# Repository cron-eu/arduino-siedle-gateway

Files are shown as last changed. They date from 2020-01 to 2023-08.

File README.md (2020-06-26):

Arduino Doorbell
====



Abstract
----

This repository holds the documentation and software needed to build a Slack interface to our Siedle Doorbell-System, using an Arduino MKR 1010 WiFi board and some electronics.

Project Folder Structure
---

* `firmware/**` Firmware for the Arduino MKR1010 WiFi Board (C++)
* `doc/*` Documentation Files (Markdown)

Author
----

Remus Lazar (rl -at- cron dot eu)

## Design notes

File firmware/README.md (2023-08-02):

Arduino Doorbell Firmware
====

Abstract
----

Firmware related documentation, how to build and configure the Hardware for operation.

#### Development Setup

Instructions how to setup the whole project (install platformio, CLion related stuff) can be found [here](../doc/Setup.md).

Device Setup and Configuration
----

An Overview about how the software and hardware works and guide to setup and configure the hardware.

Technical Overview
---

### Receive

The Arduino uses a simple hardware for the power supply and also for converting the Siedle Bus voltage to a range compatible with the SAMD21 micro (which uses 3.3V supply).

Using an ISR (interrupt service routine) the Arduino Firmware listens on the Siedle bus and captures all incoming messages, posting them using MQTT.

The messaged posted are simple JSON messages like:

```json
{
 "ts": 1580122760,
 "cmd": 1151144720
}
``` 

`ts` being the unix timestamp (UTC, synchronized via NTP), the `cmd` being the command itself - which is a 32 Bit unsigned integer.

The communication with the AWS MQTT Broker is encrypted with an X.509 certificate (see below).

### Transmit

Currently not implemented, WIP.

### Crypto Chip, X.509 Certificate (MKR Series)

To use X.509 certificates for authentication it is required that the ECC608A crypto element is configured and locked.

#### Generate the Private Key

Note: Since the private key is generated inside the crypto element it never leaves the device and is stored securely and cannot be read.

See [Configuring and Adding the Board to AWS IoT Core](https://create.arduino.cc/projecthub/Arduino_Genuino/securely-connecting-an-arduino-mkr-wifi-1010-to-aws-iot-core-a9f365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) for how to do this.

In a nutshell:
* Open the Arduino IDE
* Install the `ArduinoECCX08` Library and dependencies
* Select the MKR WiFi 1010 Board from the menu
* RUN File -> Examples -> ArduinoECCX08 -> Tools -> ECCX08CSR
* Use the Name "ArduinoDoorbell" for the "Common Name", all other fields can be left blank
* Copy the generated CSR text including "-----BEGIN CERTIFICATE REQUEST-----" and "-----END CERTIFICATE REQUEST-----" and save it locally.

### Crypto, X.509 Certificates (ESP8266)

See [Marrying ESP8266 & AWS IoT Blog Post](https://medium.com/@jgillard/marrying-esp8266-aws-iot-69f1ab219c2).

In a nutshell:

Go to the AWS IoT console, create a new device and create also the certificates, then:

```bash
cid=d9f9d3a15a
openssl x509 -in ~/Downloads/${cid}-certificate.pem.crt -out data/cert.der -outform DER 
openssl rsa -in ~/Downloads/${cid}-private.pem.key -out data/private.der -outform DER
openssl x509 -in ~/Downloads/AmazonRootCA1.pem.txt -out data/ca.der -outform DER
```

To upload the certificates:

```bash
pio run -e esp --target uploadfs
```

#### Existing Devices

* Arduino MKR WIFI 1010
  * Common Name: "ArduinoDoorbell"
* Arduino nano 33
  * Common Name: "ArduinoDoorbellNano"
* ESP8266 d1-mini
  * Common Name: "ArduinoDoorbellESP"

"Every Day" Actions
----

### Build and Upload

There are two targets in the Makefile for that: `make build` and `make upload`.

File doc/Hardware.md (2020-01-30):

Arduino Doorbell, Hardware
====

Arduino
----

### [ARDUINO MKR WIFI 1010](https://store.arduino.cc/arduino-mkr-wifi-1010)

<p>
  
</p>

See the [Getting Started](https://www.arduino.cc/en/Guide/MKRWiFi1010) document for a broad overview which available libraries are already available for this board.

### [ARDUINO NANO 33 IOT](https://store.arduino.cc/arduino-nano-33-iot)

<p>
  
</p>

Arduino related
----

* [Securely Connecting an Arduino MKR WiFi 1010 to AWS IoT Core](https://create.arduino.cc/projecthub/Arduino_Genuino/securely-connecting-an-arduino-mkr-wifi-1010-to-aws-iot-core-a9f365)

* [ArduinoMqttClient Library for Arduino](https://github.com/arduino-libraries/ArduinoMqttClient)

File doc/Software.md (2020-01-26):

WiFi/MQTT Software and Libraries
====

MQTT, SSL and related libraries
----

* [Official Arduino MQTT Library](https://github.com/arduino-libraries/ArduinoMqttClient)
* [ArduinoMqttClient Library for Arduino](https://github.com/arduino-libraries/ArduinoMqttClient)
* [ArduinoBearSSL](https://github.com/arduino-libraries/ArduinoBearSSL)
* [ArduinoECCX08](https://github.com/arduino-libraries/ArduinoECCX08)

Arduino Cloud Provider Examples
----

See https://github.com/arduino/ArduinoCloudProviderExamples

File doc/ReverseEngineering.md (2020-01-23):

Reverse Engineering Insights
====

Siedle 1+n protocol
----

Basically this uses different voltages to signalize the events, e.g. "ringing".

* [Offizielles Systemhandbuch](https://www.siedle.de/xs_db/DOKUMENT_DB/www/Systemhandbuch/1+n_2013/Systemhandbuch_1+n-Technik_136441_DE.pdf)
* [Klingelanlage: Siedle "1+n" Protokoll  (DE)](https://www.mikrocontroller.net/topic/264481)
* [Reverse engineering of the Siedle HTA 811-0 W (DE)](https://www.richis-lab.de/Siedle.htm)

Siedle In-Home-Bus Protokoll
----

Newer Siedle devices use a bus protocol called "In-Home-Bus". The bus is a 2-wire bus and uses a supply voltage of 28V. Devices do communicate via monitoring the bus voltage and also pulling down the bus to transmit individual bits.

The cheapest Siedle Device is the BTS 850 (~50 €).

There is a blog post on mikrocontroller.net about [building a WiFi enabled MQTT Gateway](https://www.mikrocontroller.net/topic/308271) based on an Arduino, the C source code also [being available](https://www.mikrocontroller.net/attachment/360089/siedle-client.ino).

### Gyrator Circuit

See the [Eingangskondensator dämpft Audio auf Busleitung](https://www.mikrocontroller.net/topic/343694) form article for details.

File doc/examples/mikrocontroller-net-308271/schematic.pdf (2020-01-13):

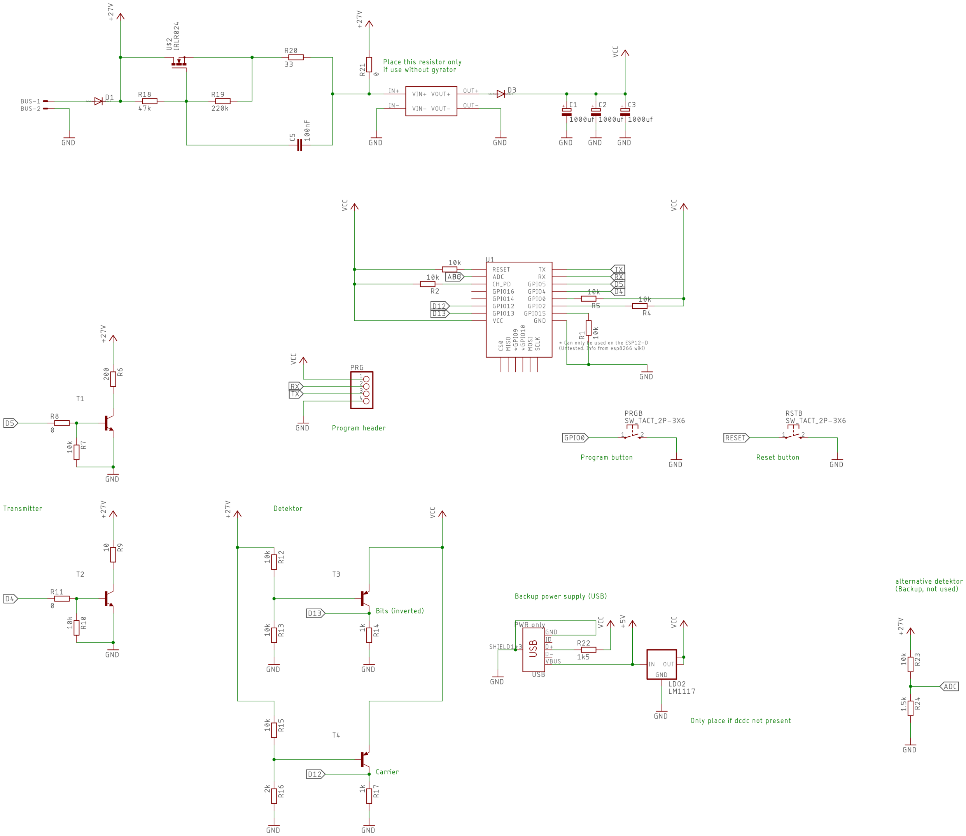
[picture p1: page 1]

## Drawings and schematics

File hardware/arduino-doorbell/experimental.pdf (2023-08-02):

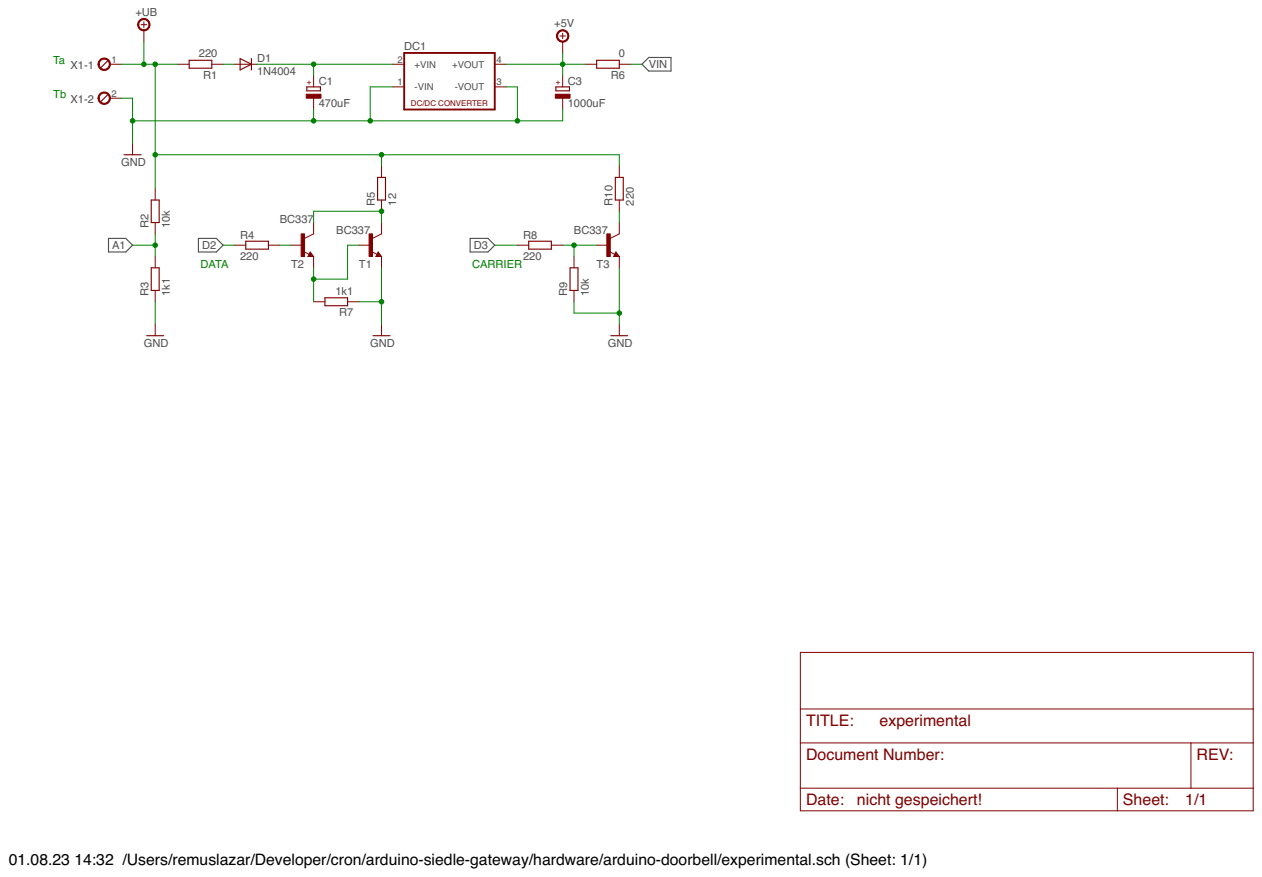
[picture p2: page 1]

Document Number: | REV:

Date: nicht gespeichert! | Sheet: 1/1

01.08.23 14:32 /Users/remuslazar/Developer/cron/arduino-siedle-gateway/hardware/arduino-doorbell/experimental.sch (Sheet: 1/1)

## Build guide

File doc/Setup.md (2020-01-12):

Setup Dev Environment
====

### PlatformIO and related

This project uses [PlatformIO Core](https://platformio.org/install/cli) for development. The [setup process](https://docs.platformio.org/en/latest/installation.html) (on a Mac) is straightforward:

```bash
pip install -U --user platformio
```

Make sure you do already have the Python 2.7 bin dir (`$HOME/Library/Python/2.7/bin`) in `$PATH`.

Development and Upload
----

CLion IDE is being used for development. The device firmware is in the `firmware/` folder. Chdir to `firmware` and then:

```bash
platformio update

# if using CLion
platformio init --ide clion --board mkrwifi1010 # this will create the excluded file CMakeListsPrivate.txt
```

To e.g. upload a new firmware via USB, do:

```bash
platformio run --target upload --upload-port /dev/cu.usbmodem14701
```

Clion IDE
--

Install [CLion](https://www.jetbrains.com/clion/) (optional).

Note: the Clion IDE is useful for development, but not a hard requirement, a regular Editor, e.g. atom is also fine.

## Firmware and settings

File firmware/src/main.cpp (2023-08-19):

#include <Arduino.h>
#include <serial-debug.h>

#include <WebServer.h>
#include <time.h>

#ifdef ARDUINO_ARCH_SAMD
#include <WDTZero.h>
#endif

#include "siedle-log.h"
#include "led.h"
#include "wifi-manager.h"
#include "rtc.h"
#include "siedle-service.h"
#include "web-ui.h"
#include "main_profiling.h"

#ifdef USE_MQTT
#include "mqtt-service.h"
#endif

WebServer webServer(80);
#ifdef ARDUINO_ARCH_SAMD
WDTZero Watchdog;
#endif

void __unused setup() {
    Debug.begin();

    DEBUG_PRINTLN("Booting..");

    LED.begin();
    SiedleService.begin();

    #ifdef ARDUINO_ARCH_SAMD
    RTCSync.begin();
    WiFiManager.begin();
    #else
    WiFiManager.begin();
    RTCSync.begin();
    #endif

#ifdef USE_MQTT
    MQTTService.begin();
#endif

    webServer.rootPageHandler = webUIHTMLHandler;
    webServer.begin();
#ifdef ARDUINO_ARCH_SAMD
    Watchdog.setup(WATCHDOG_SETUP);
#endif

}

#ifdef ARDUINO_ARCH_SAMD
void inline wdtLoop() {
    static unsigned long lastMillis = 0;
    if (millis() - lastMillis > 250) {
        lastMillis = millis();
        Watchdog.clear();
    }
}
#endif



void __unused loop() {
    unsigned long loop_start_millis = millis();
    LED.loop();
    WiFiManager.loop();
    RTCSync.loop();
    SiedleService.loop();
#ifdef USE_MQTT
    MQTTService.loop();
#endif
    webServer.loop();

#ifdef ARDUINO_ARCH_SAMD
    wdtLoop();
#endif
    unsigned long loop_duration = millis() - loop_start_millis;

    if (loop_duration > max_main_loop_duration_ms) {
        max_main_loop_duration_ms = loop_duration;
    }

}

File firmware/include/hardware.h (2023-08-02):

//
// Created by Remus Lazar on 27.01.20.
//
// Hardware related settings, GPIO Pin numbers etc.
//

#ifndef FIRMWARE_HARDWARE_H
#define FIRMWARE_HARDWARE_H


#ifdef DEVICE_ARDUINO_MKR_1010
#define SIEDLE_A_IN A1
#define SIEDLE_TX_PIN 0
#define SIEDLE_TX_CARRIER_PIN 3

#elif defined(ARDUINO_SAMD_NANO_33_IOT)
#define SIEDLE_TX_PIN 2
#define SIEDLE_TX_CARRIER_PIN 3
#define SIEDLE_A_IN A1

#elif defined(ARDUINO_ESP8266_WEMOS_D1MINI)
#define SIEDLE_A_IN A0
#define SIEDLE_TX_PIN D5
#define SIEDLE_TX_CARRIER_PIN D6
#endif

#endif //FIRMWARE_HARDWARE_H

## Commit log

2020-01-09 Main Arduino sketch and Clion IDE .idea settings
2020-01-09 Makefile added to install the arduino core and required libraries
2020-01-09 Basic main sketch implemented
    this implements a basic web-server which prints out the battery voltage as a POC.
2020-01-09 Use Arduino Scheduler, statusLED Loop implemented
2020-01-11 Battery Voltage tweaks
2020-01-23 Eagle Project added, gyrator circuit
    [arduino-doorbell.sch]
2020-01-23 Eagle Schematic update
    [arduino-doorbell.sch]
2020-01-24 Schematic for experiments added
    [experimental.sch]
2020-01-24 WebServer printDebug callback function implemented
2020-01-25 SiedleClient.cpp tweaks
    threshold voltage tweaks, logic, ..
2020-01-25 First working version..
    various bugfixes and improvements, use of the avdweb_AnalogReadFast library for faster ADC
    [main.cpp]
2020-01-25 Eagle files update
    [experimental.sch]
2020-01-25 Better WL_NO_MODULE error handling
    [main.cpp]
2020-01-26 Minor bugfix in printDebug: do not show empty slots
    [main.cpp]
2020-01-27 MQTT rx logic commented out
    we will implement this on a later stage.
2020-01-28 Use a hardware timer to fix timing issues
    Having ISRs which takes longer than 100-20 microseconds causes issues with other libraries which rely on exact timing and will also interfere with the millis() logic.
2020-01-29 LED status loop tweaks
2020-01-29 mqtt sending logic bugfix
    available is always being true, size() is the right one..
    [main.cpp]
2020-01-30 ARDUINO NANO 33 added to the documentation
2020-01-30 Arduino nano 33 board added
2020-02-01 Make onMessageReceived() logic more robust
    use the supplied messageSize param to determine how many chars to read from client and also fixes a compiler warning.
    [main.cpp]
2020-02-01 Lambda functions add-ons
    - parse the siedle command logic implemented
    - print out "debug info" conditionally
2020-02-01 Carrier handling circuit implemented (eagle)
    [experimental.sch]
2020-02-01 Streamline schematic values
    [experimental.sch]
2020-02-03 HW Watchdog timer implemented
2020-02-03 Print out the WiFiNINA Firmware Version
2020-02-04 Fix constructor chaining logic
2020-02-04 Fix Build issues
    make sure to define all variables in the main.cpp
    [main.cpp]
2020-06-30 Streamline project with the current platformio version
2020-06-30 Refactor the Serial.print* calls to a separate class
2020-06-30 Use distinct sections for each board in hardware.h
2020-06-30 Take care of the builtin LED specifics on ESPs
2020-06-30 Refactor wifi-manager connection logic
    this also adds mDNS support (currently only for ESP8266)
2020-06-30 Fix a bug in the LED logic
    the LED should blink / 250ms when NOT connected.
    [led.h]
2020-06-30 Print ntp debug message only once if not initialized
2023-08-01 Add the schematic PDF
2023-08-01 Refactor the mqtt service for current SSL libs
2023-08-01 Pin libraries to older versions
2023-08-01 Pin libs to latest available version
2023-08-02 Add the current cronAppDoorbellHandler JS code
2023-08-03 Rework the SiedleClient ISR Logic
    Make some vars volatile and ensure that we disable interrupts while accessing vars used by the iSR.
2023-08-03 Rework the interrupts enable/disable logic
2023-08-03 Use 256dpi/MQTT instead of arduino-libraries/ArduinoMqttClient
2023-08-04 Use the hostname from the secrets file instead of "arduino"
2023-08-04 Use a 16 seconds hardware watchdog timer
2023-08-04 Configure MQTT Client socket timeout
2023-08-05 Disable WiFi low power mode
2023-08-06 Revert settings (RTS and WiFi low power)
    The change was a test to see if it helps to avoid the reboots. Did not
2023-08-06 Rework the sent ack via mqtt logic
    Do not send the cmd to mqtt to the sent topic if the siedle client has not increased the tx counter (handle the error case here)
2023-08-07 Revert the watchdog timeout setting to 16s
    [main.cpp]
2023-08-13 Refactor the webserver request parsing to save memory
    we do not really need the request header at all, so rework the logic
    to save memory on our quite constrained device.
2023-08-13 Fix a bug in the webserver currentline length logic
